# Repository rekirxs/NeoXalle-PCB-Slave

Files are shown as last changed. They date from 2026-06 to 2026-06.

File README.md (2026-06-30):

# NeoXalle-PCB-Slave

A full PCB work for a sport sensorial reaction device called NeoXalle.

Similar products exist in the market such as BlazePod and Fitlight, based on this projects but with upgrades for the better.

NeoXalle is a sport training device made up of 4 pods with LEDS, accelerometers, vibratiion motors and speaker to simulate a training for a variety of sports, all controlled thru an mobile APP where the user has the full control of the pods and can direct the training at any tipe of likings.

The purpose of this pcb is to transform the actual circuit wired phisically into a pcb more compact and more capable than the already existing one.

**Overview**

This repository contains the design files and the images of each part.

Watch the video (https://youtu.be/leAVq9ZJ1fE)

### [Watch this video on YouTube](https://youtu.be/leAVq9ZJ1fE)
**Screenshots**

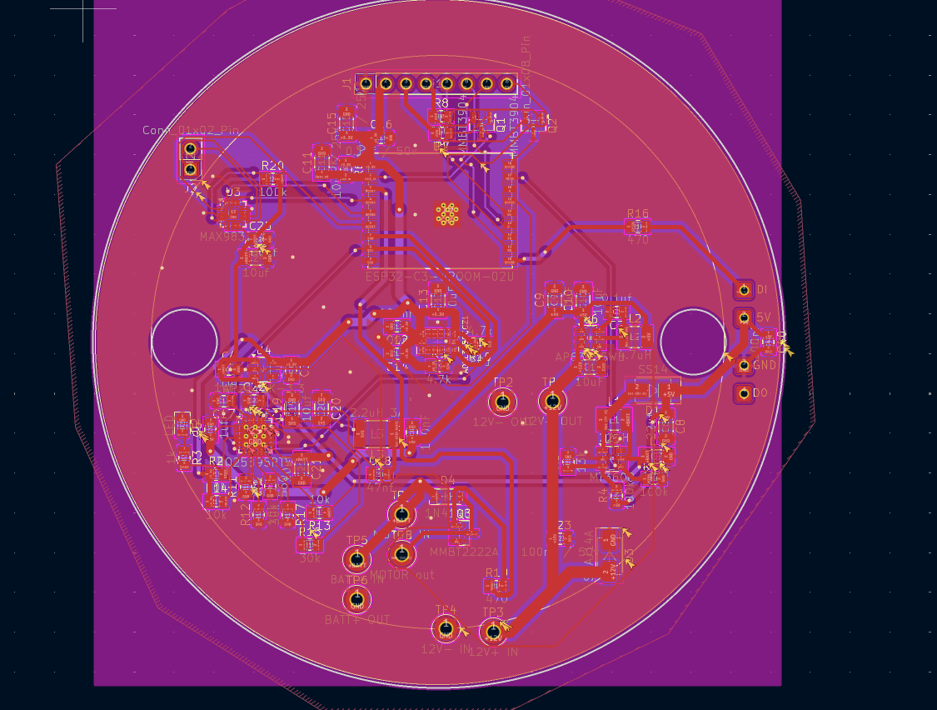
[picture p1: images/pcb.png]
Overall design


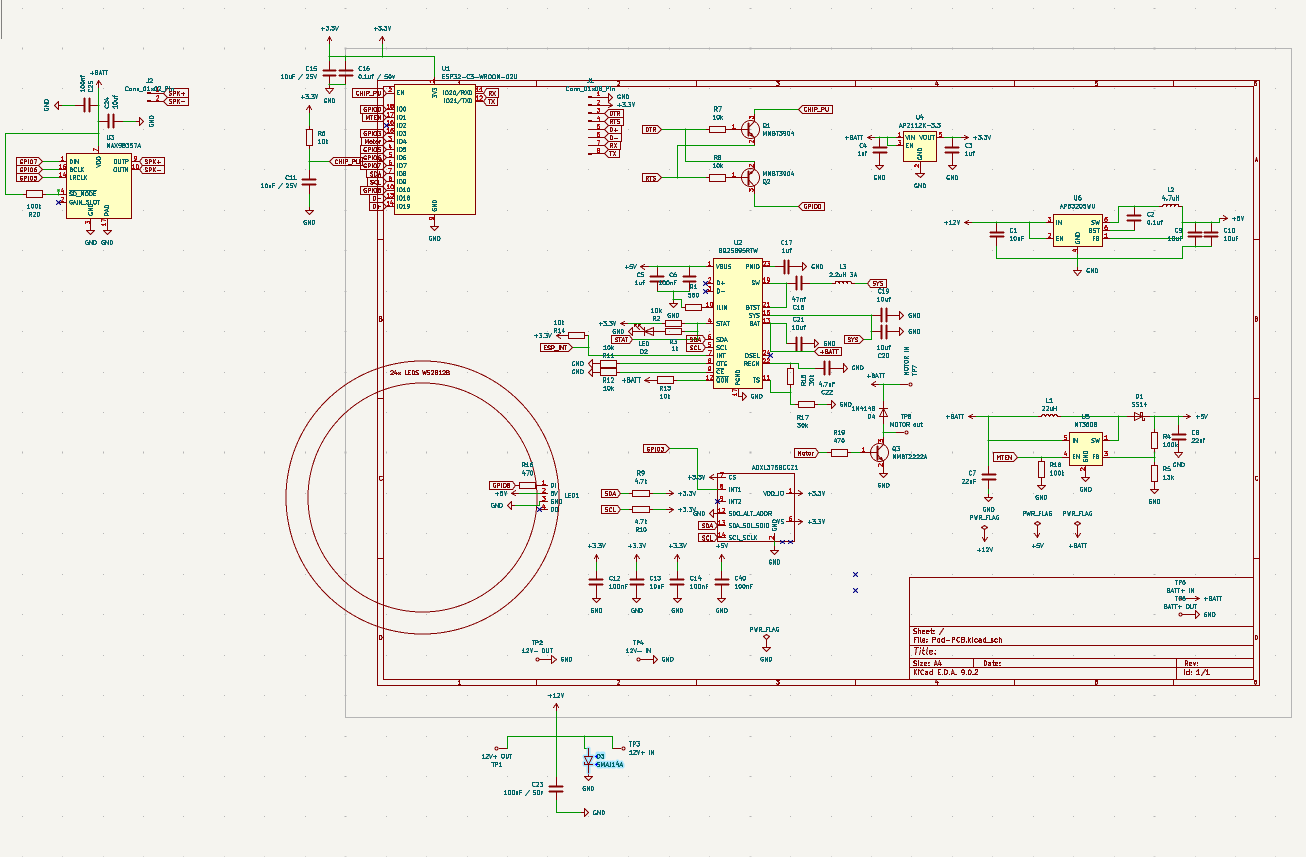
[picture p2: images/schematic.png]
Schematic


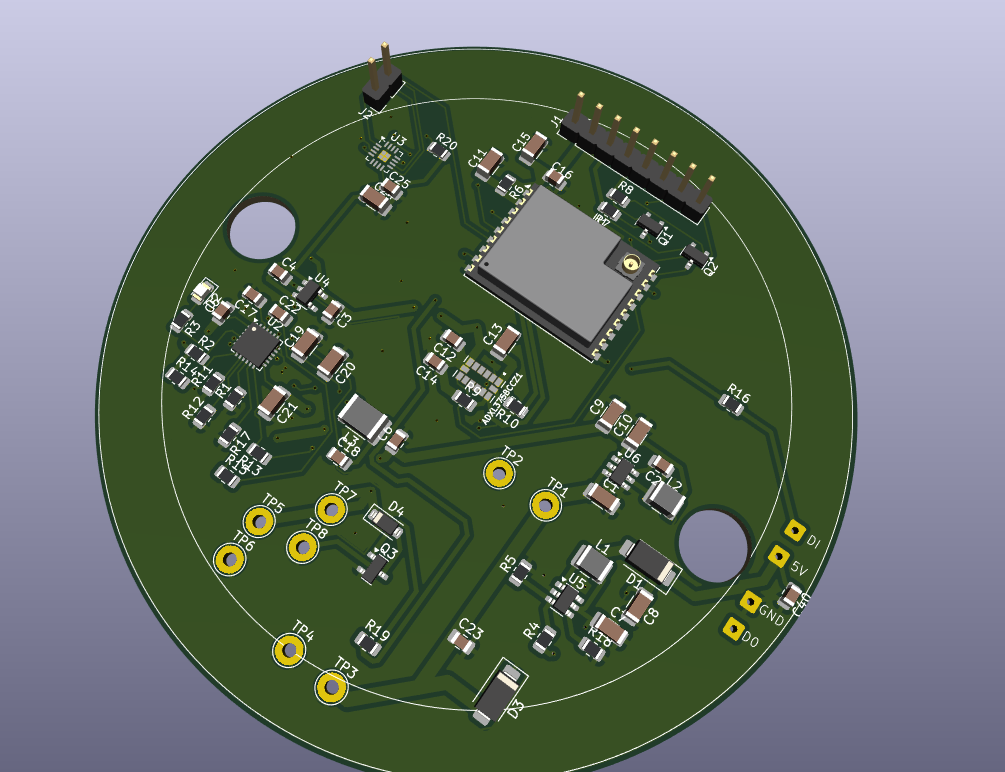
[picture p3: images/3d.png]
3D


CSV FOUND AS FILE AS WELL

|Item |Description |Quantity|Unit Price ($)|Total Price ($)|URL |Running Total|
|---|---|---|---|---|---|---|
|ESP32-C3 WROOOM 02u |Microcontroller |5 |1.785 |19.00 |https://es.aliexpress.com/item/1005004386637738.html|19.00 |
|ADXL375 |Acelerometer |5 |7.2 |36.0 |https://es.aliexpress.com/item/1005011998515044.html|55.00 |
|BQ25895RTW |Battery Charger IC |5 |1.73 |8.65 |https://es.aliexpress.com/item/1005007164079601.html|63.65 |
|PCB |PCB |5 |7.2 |36 |https://cart.jlcpcb.com/shopcart/cart/ |99.65 |

**Repository layout**

- `pcb/` — KiCad schematic and PCB files-
- `images/` — project screenshots used by this README

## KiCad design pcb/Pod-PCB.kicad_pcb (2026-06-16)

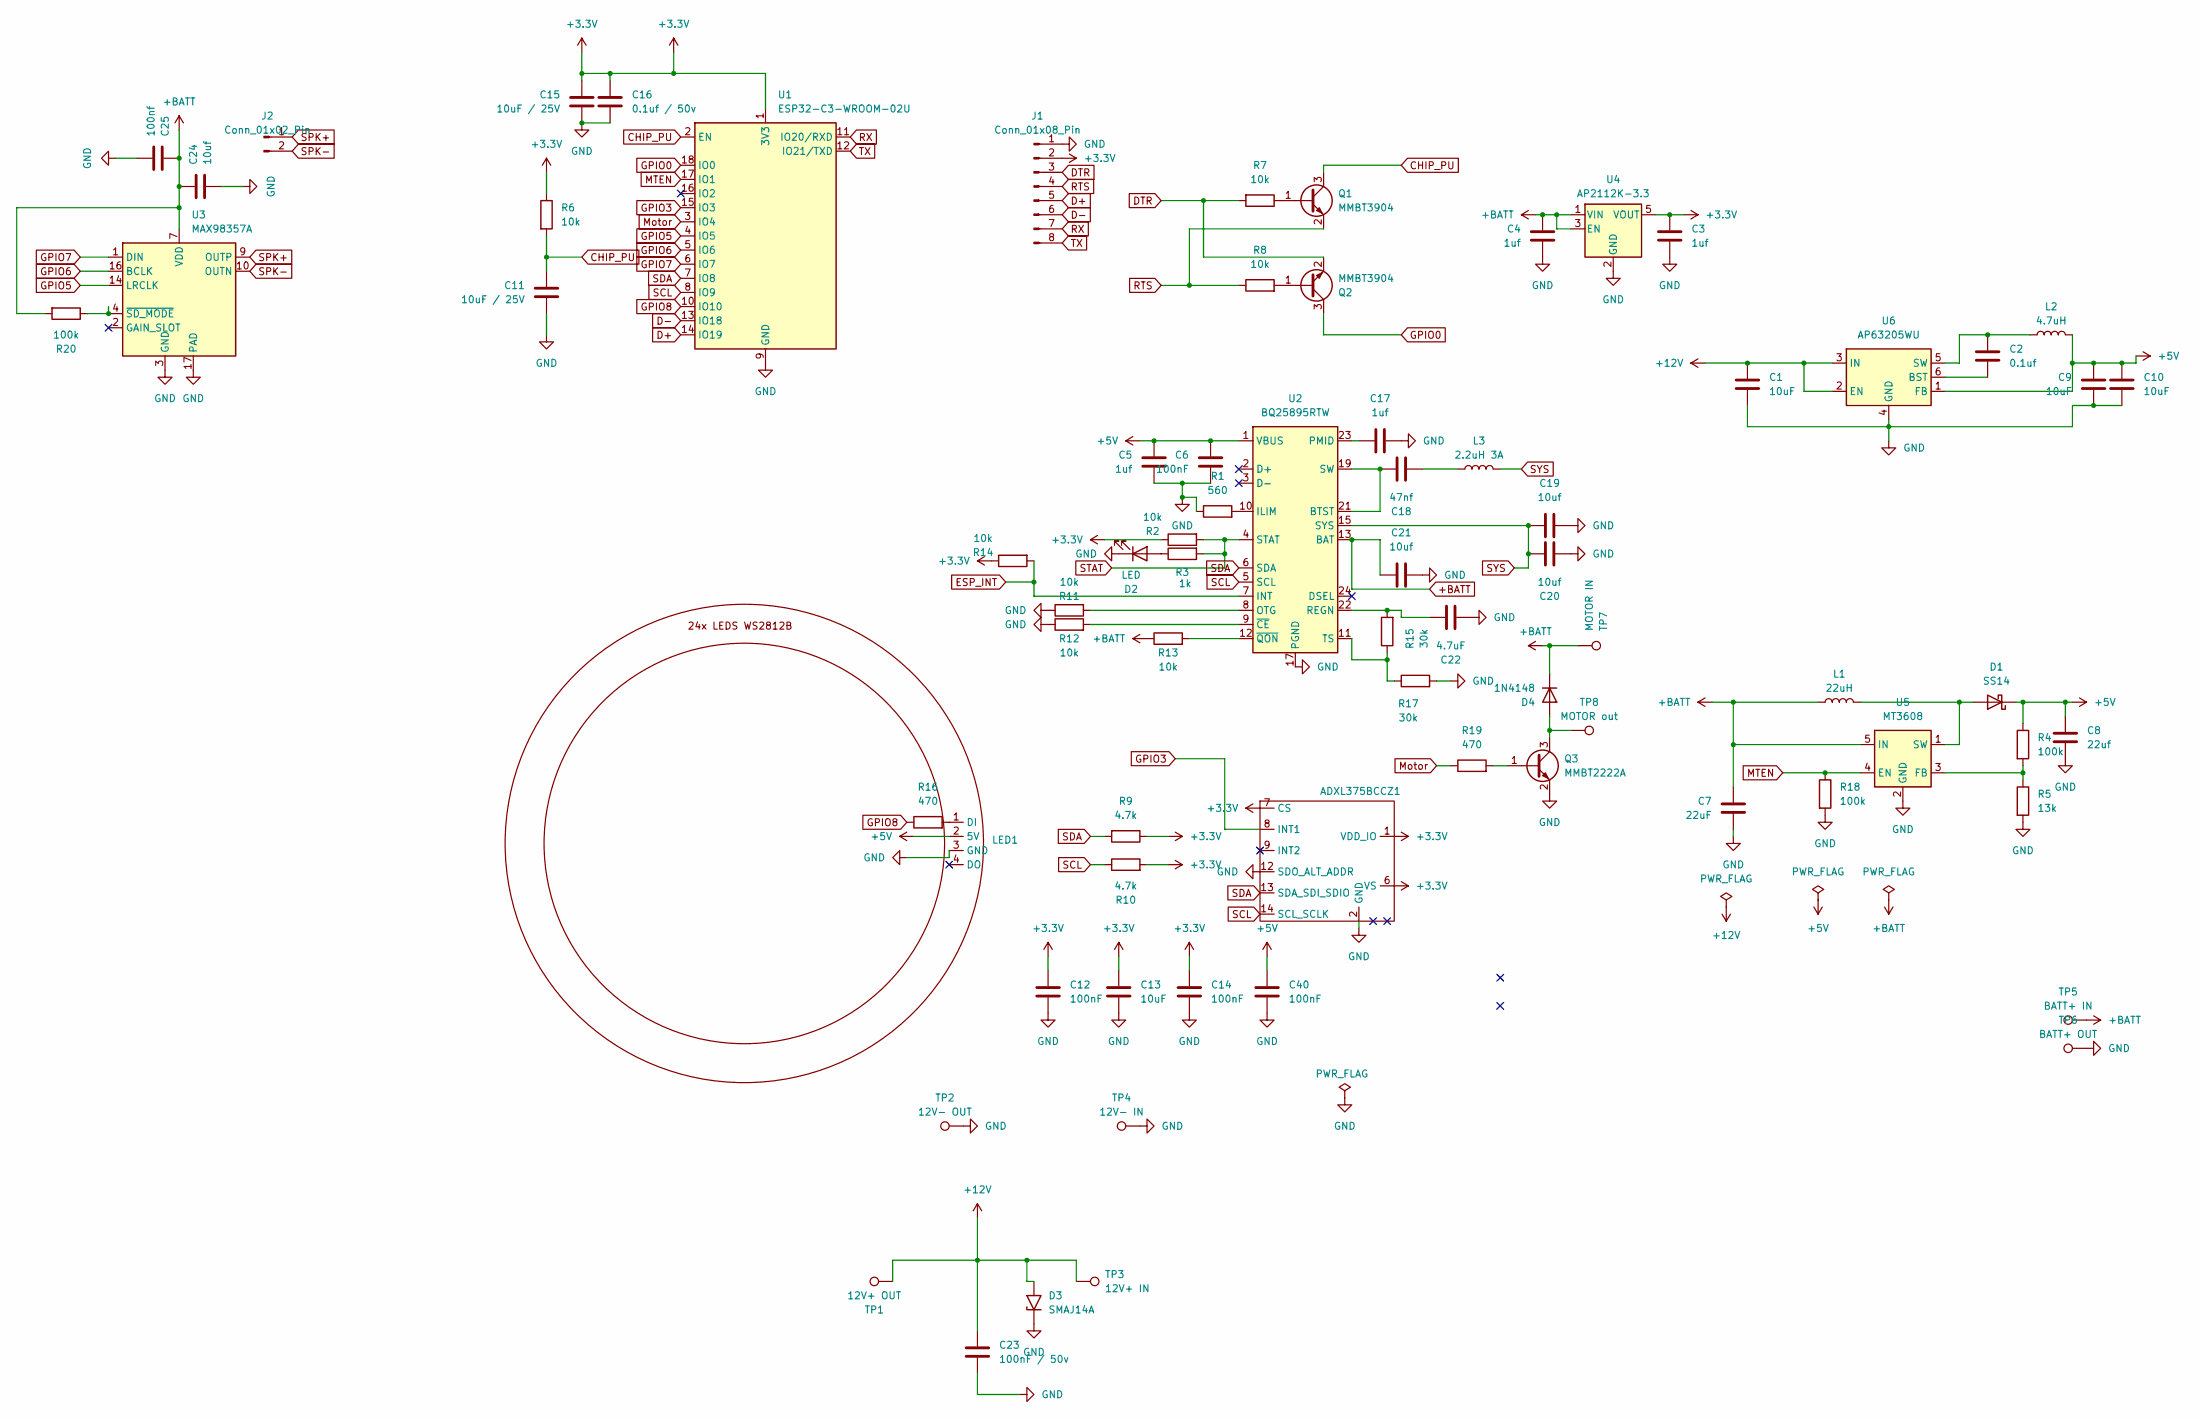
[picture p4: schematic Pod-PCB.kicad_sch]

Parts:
ADXL375BCCZ1: PQFN80P500X300X100-14N
C1, C9, C10, C13: 10uF; C_1206_3216Metric
C2: 0.1uf; C_0805_2012Metric
C3, C4, C5, C17: 1uf; C_0805_2012Metric
C6, C12, C14, C40: 100nF; C_0805_2012Metric
C7: 22uF; C_1206_3216Metric
C8: 22uf; C_1206_3216Metric
C11, C15: 10uF / 25V; C_1206_3216Metric
C16: 0.1uf / 50v; C_0805_2012Metric
C18: 47nf; C_0805_2012Metric
C19, C20, C21, C24: 10uf; C_1206_3216Metric
C22: 4.7uF; C_0805_2012Metric
C23: 100nF / 50v; C_0805_2012Metric
C25: 100nf; C_0805_2012Metric
D1: SS14; D_SMA
D2: LED; LED_0805_2012Metric
D3: SMAJ14A; D_SMA
D4: 1N4148; D_DO-35_SOD27_P7.62mm_Horizontal
J1: Conn_01x08_Pin; PinHeader_1x08_P2.54mm_Vertical
J2: Conn_01x02_Pin; PinHeader_1x02_P2.54mm_Vertical
L1: 22uH; L_1210_3225Metric
L2: 4.7uH; L_1210_3225Metric
L3: 2.2uH 3A; L_1812_4532Metric
LED1: Untitled
Q1, Q2: MMBT3904; SOT-23
Q3: MMBT2222A; SOT-23
R1: 560; R_0805_2012Metric
R2, R6, R7, R8, R11, R12, R13, R14: 10k; R_0805_2012Metric
R3: 1k; R_0805_2012Metric
R4, R18, R20: 100k; R_0805_2012Metric
R5: 13k; R_0805_2012Metric
R9, R10: 4.7k; R_0805_2012Metric
R15, R17: 30k; R_0805_2012Metric
R16, R19: 470; R_0805_2012Metric
TP1: 12V+ OUT; TestPoint_THTPad_D3.0mm_Drill1.5mm
TP2: 12V- OUT; TestPoint_THTPad_D3.0mm_Drill1.5mm
TP3: 12V+ IN; TestPoint_THTPad_D3.0mm_Drill1.5mm
TP4: 12V- IN; TestPoint_THTPad_D3.0mm_Drill1.5mm
TP5: BATT+ IN; TestPoint_THTPad_D3.0mm_Drill1.5mm
TP6: BATT+ OUT; TestPoint_THTPad_D3.0mm_Drill1.5mm
TP7: MOTOR IN; TestPoint_THTPad_D3.0mm_Drill1.5mm
TP8: MOTOR out; TestPoint_THTPad_D3.0mm_Drill1.5mm
U1: ESP32-C3-WROOM-02U
U2: BQ25895RTW; Texas_RTW_WQFN-24-1EP_4x4mm_P0.5mm_EP2.7x2.7mm_ThermalVias
U3: MAX98357A; TQFN-16-1EP_3x3mm_P0.5mm_EP1.23x1.23mm
U4: AP2112K-3.3; SOT-23-5
U5: MT3608; SOT-23-6
U6: AP63205WU; TSOT-23-6

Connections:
+3.3V: ADXL375BCCZ1.1 (VDD_IO), ADXL375BCCZ1.6 (VS), ADXL375BCCZ1.7 (CS), C3.1, C12.1, C13.1, C14.1, C15.1, C16.1, J1.2, R2.1, R6.1, R9.1, R10.2, R14.1, U1.1 (3V3), U4.5 (VOUT)
+5V: C5.1, C6.1, C8.1, C9.1, C10.1, C40.1, D1.1 (K), L2.2, LED1.2 (5V), R4.1, U2.1 (VBUS), U6.1 (FB)
+12V: C1.1, C23.1, D3.2 (A2), TP1.1, TP3.1, U6.2 (EN), U6.3 (IN)
+BATT: C4.1, C7.1, C21.1, C24.1, C25.1, D4.1 (K), L1.2, R13.1, R20.2, TP5.1, TP7.1, U2.13 (BAT), U2.14 (BAT), U3.7 (VDD), U3.8 (VDD), U4.1 (VIN), U4.3 (EN), U5.5 (IN)
CHIP_PU: C11.1, Q1.3 (C), R6.2, U1.2 (EN)
D+: J1.5, U1.14 (IO19)
D-: J1.6, U1.13 (IO18)
DTR: J1.3, Q2.2 (E), R7.2
ESP_INT: R14.2, U2.7 (INT)
GND: ADXL375BCCZ1.2 (GND), ADXL375BCCZ1.12 (SDO_ALT_ADDR), C1.2, C3.2, C4.2, C5.2, C6.2, C7.2, C8.2, C9.2, C10.2, C11.2, C12.2, C13.2, C14.2, C15.2, C16.2, C17.2, C19.2, C20.1, C21.2, C22.1, C23.2, C24.2, C25.2, C40.2, D2.1 (K), D3.1 (A1), J1.1, LED1.3 (GND), Q3.2 (E), R1.1, R5.2, R11.1, R12.1, R17.2, R18.2, TP2.1, TP4.1, TP6.1, U1.9 (GND), U1.19 (GND), U2.17 (PGND), U2.18 (PGND), U2.25 (PGND), U3.3 (GND), U3.11 (GND), U3.15 (GND), U3.17 (PAD), U4.2 (GND), U5.2 (GND), U6.4 (GND); also elsewhere on the board
GPIO0: Q2.3 (C), U1.18 (IO0)
GPIO3: ADXL375BCCZ1.8 (INT1), U1.15 (IO3)
GPIO5: U1.4 (IO5), U3.14 (LRCLK)
GPIO6: U1.5 (IO6), U3.16 (BCLK)
GPIO7: U1.6 (IO7), U3.1 (DIN)
GPIO8: R16.1, U1.10 (IO10)
MTEN: R18.1, U1.17 (IO1), U5.4 (EN)
Motor: R19.1, U1.3 (IO4)
unnamed 18: C18.2, L3.1; also elsewhere on the board
unnamed: D1.2 (A), L1.1, U5.1 (SW)
unnamed: D2.2 (A), R3.1
unnamed: D4.2 (A), Q3.3 (C), TP8.1
unnamed: LED1.1 (DI), R16.2
unnamed: Q1.1 (B), R7.1
unnamed: Q2.1 (B), R8.2
unnamed: Q3.1 (B), R19.2
unnamed 26: C18.1, U2.19 (SW), U2.20 (SW), U2.21 (BTST); also elsewhere on the board
unnamed: R1.2, U2.10 (ILIM)
unnamed: R11.2, U2.8 (OTG)
unnamed 29: C17.1, U2.23 (PMID); also elsewhere on the board
unnamed: C22.2, R15.2, U2.22 (REGN)
unnamed: R15.1, R17.1, U2.11 (TS)
unnamed: R12.2, U2.9 (~CE)
unnamed: R13.2, U2.12 (~QON)
unnamed: R20.1, U3.4 (~SD_MODE)
unnamed: R4.2, R5.1, U5.3 (FB)
unnamed: C2.2, U6.6 (BST)
unnamed: C2.1, L2.1, U6.5 (SW)
RTS: J1.4, Q1.2 (E), R8.1
RX: J1.7, U1.11 (IO20/RXD)
SCL: ADXL375BCCZ1.14 (SCL_SCLK), R10.1, U1.8 (IO9), U2.5 (SCL)
SDA: ADXL375BCCZ1.13 (SDA_SDI_SDIO), R9.2, U1.7 (IO8), U2.6 (SDA)
SPK+: J2.1, U3.9 (OUTP)
SPK-: J2.2, U3.10 (OUTN)
STAT: R2.2, R3.2, U2.4 (STAT)
SYS: C19.1, C20.2, L3.2, U2.15 (SYS), U2.16 (SYS)
TX: J1.8, U1.12 (IO21/TXD)

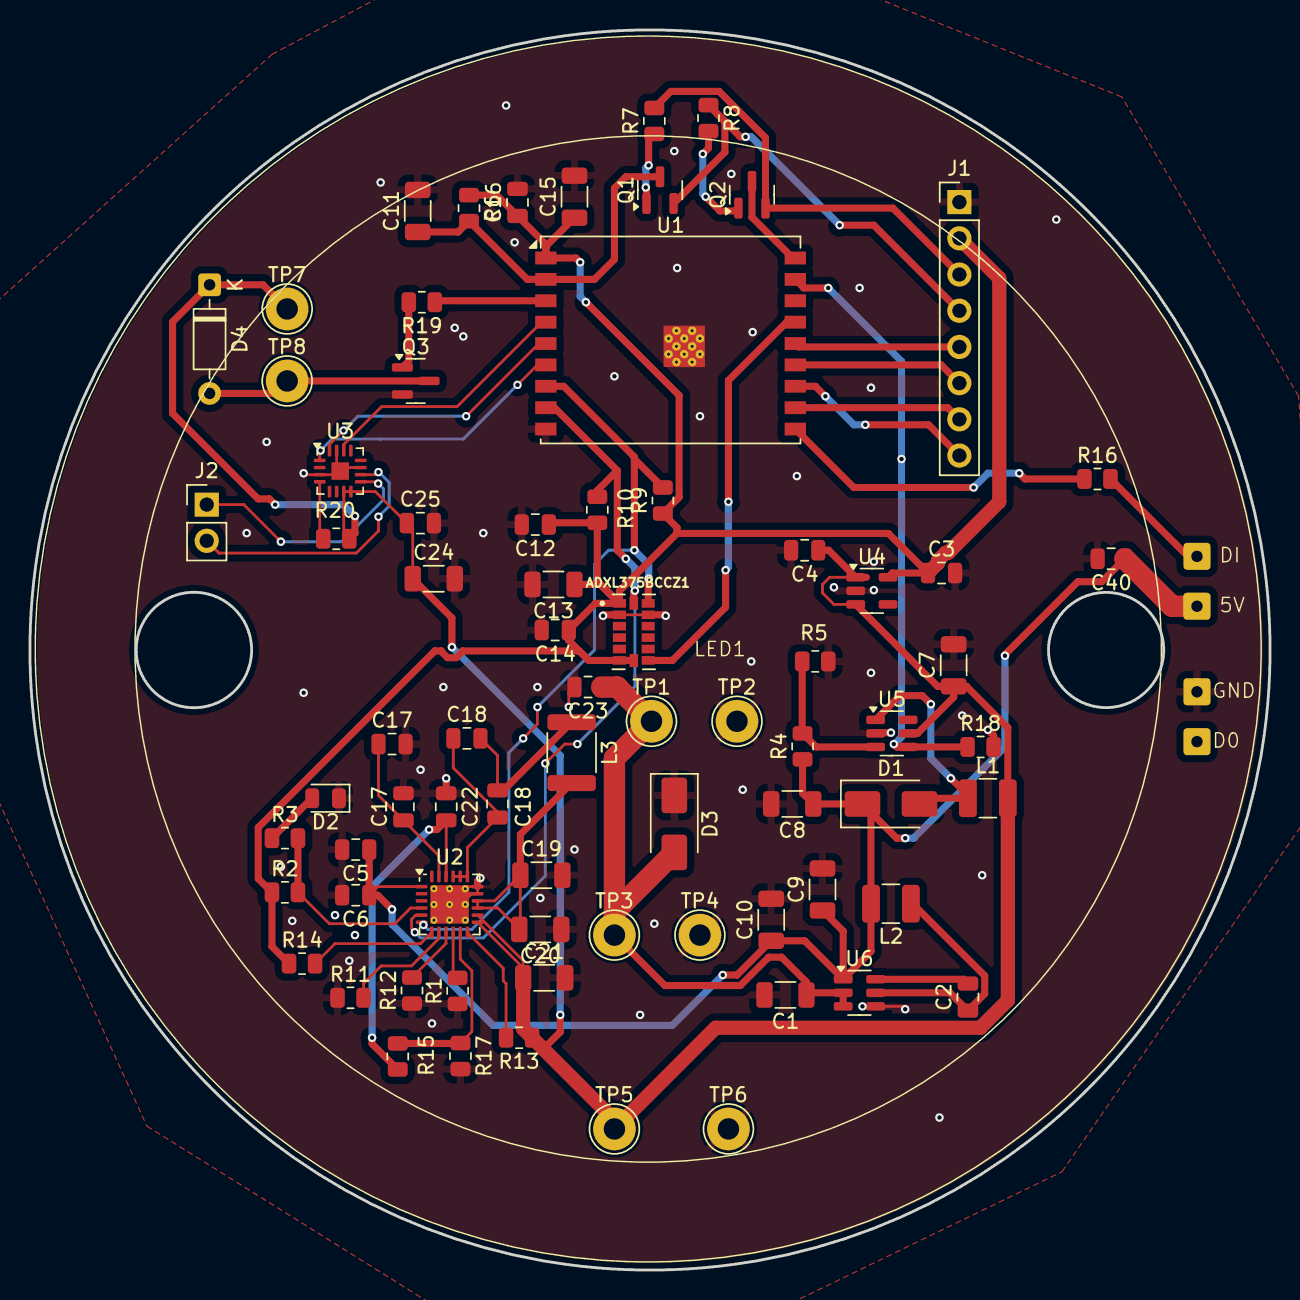
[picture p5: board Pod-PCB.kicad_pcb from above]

Board: 2 copper layers, 87.0 x 87.0 mm, 76 parts (0 on the bottom side), 47 nets.

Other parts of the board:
C17#2: 1uf; C_0805_2012Metric
C18#2: 47nf; C_0805_2012Metric

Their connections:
GND: C17#2.2; also elsewhere on the board
unnamed 18: C18#2.2; also elsewhere on the board
unnamed 26: C18#2.1; also elsewhere on the board
unnamed 29: C17#2.1; also elsewhere on the board
